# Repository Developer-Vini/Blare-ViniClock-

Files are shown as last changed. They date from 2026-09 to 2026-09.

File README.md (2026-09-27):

# Blare(ViniClock)

# What is ViniClock?

ViniClock is an alarm clock to wake me up whenever I have to go to school; I don't want to miss the bus.

## Some views of the project:

### CASE 3D
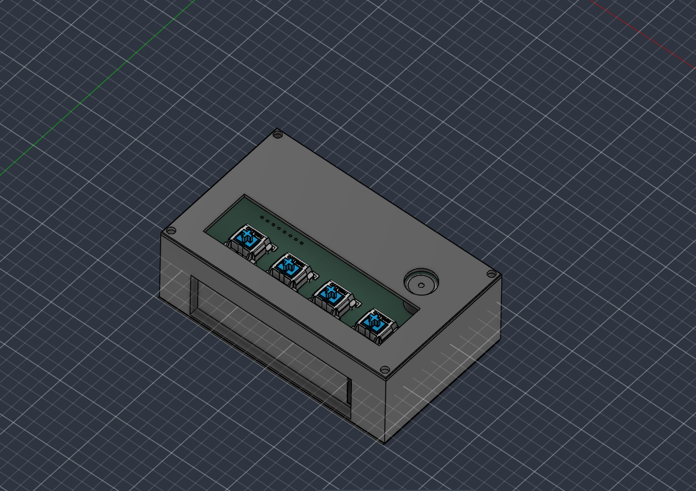
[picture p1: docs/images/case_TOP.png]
top

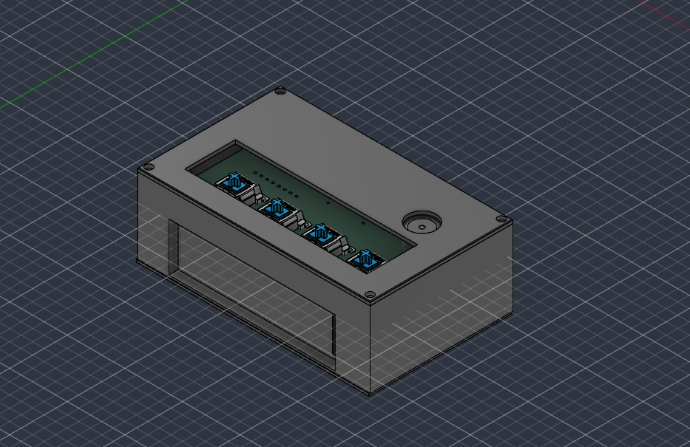
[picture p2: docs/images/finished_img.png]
finished_img


## Assembly CASE 3D:
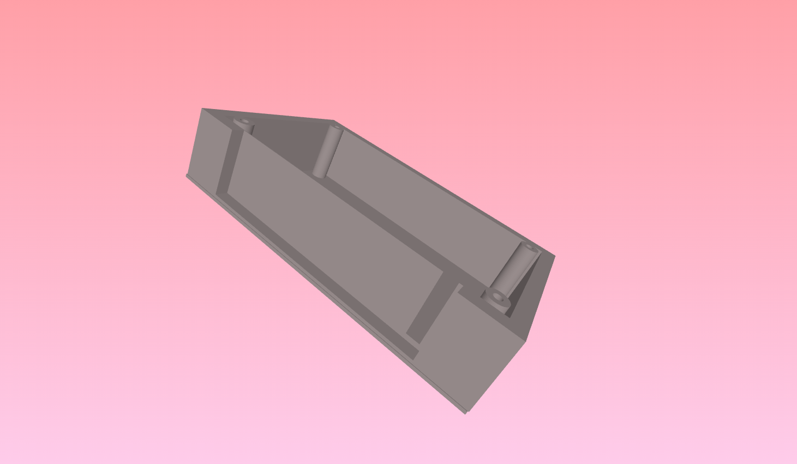
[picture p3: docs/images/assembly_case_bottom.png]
BOTTOM

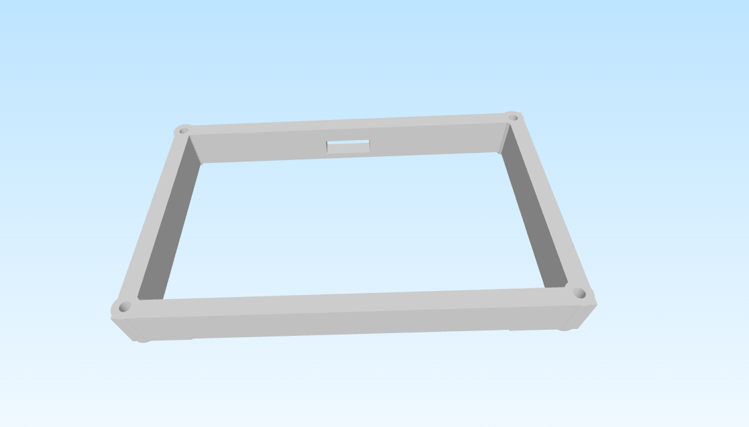
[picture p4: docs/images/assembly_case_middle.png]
MIDDLE

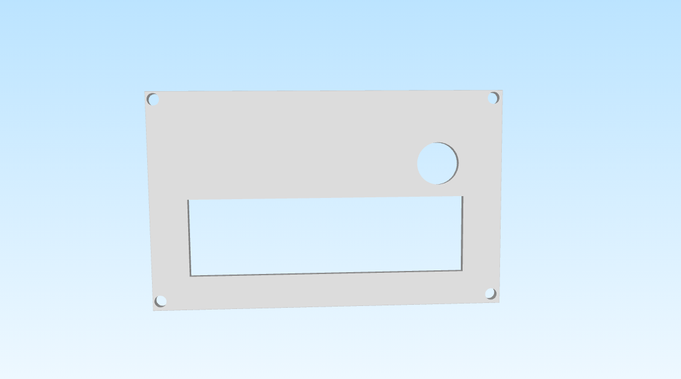
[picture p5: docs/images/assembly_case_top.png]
TOP


### PCB 3d
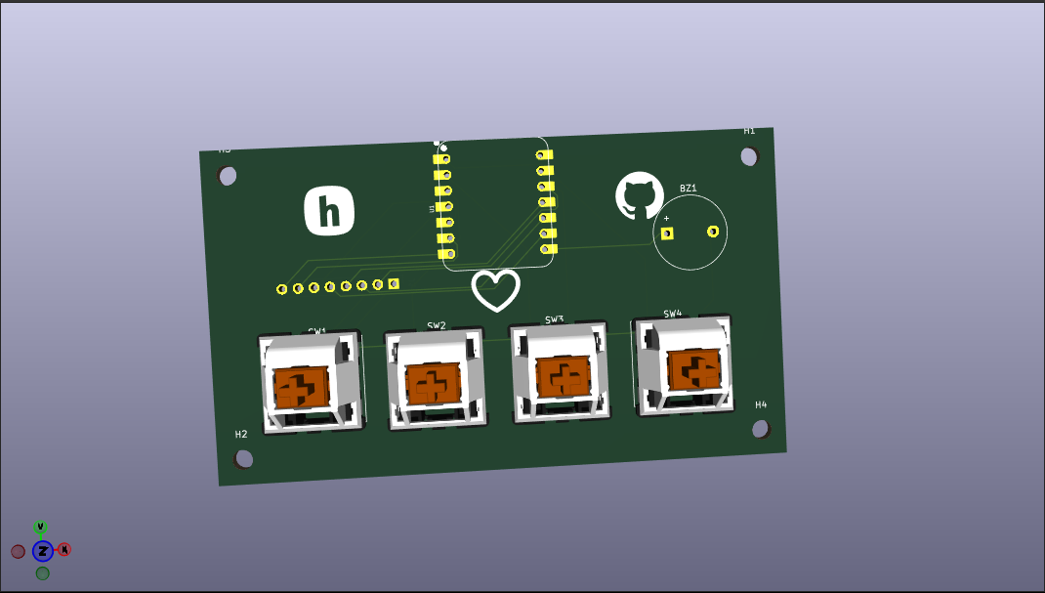
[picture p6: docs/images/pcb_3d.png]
pcb_3d_view

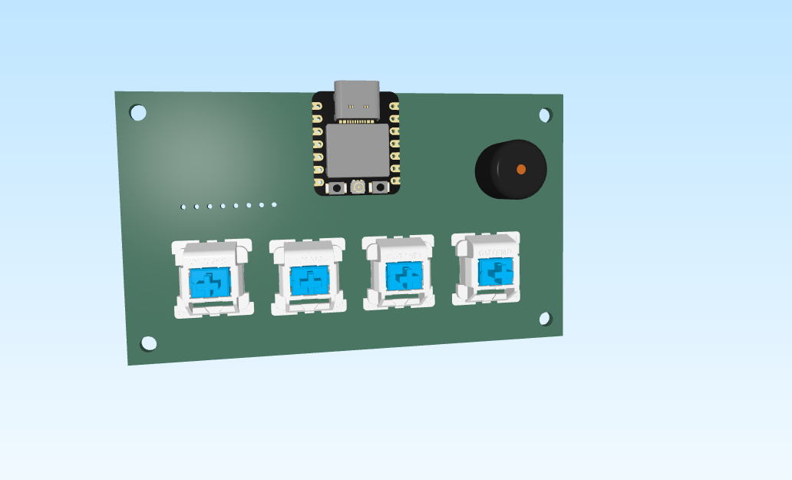
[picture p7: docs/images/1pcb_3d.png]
1pcb_3d_view


### PCB
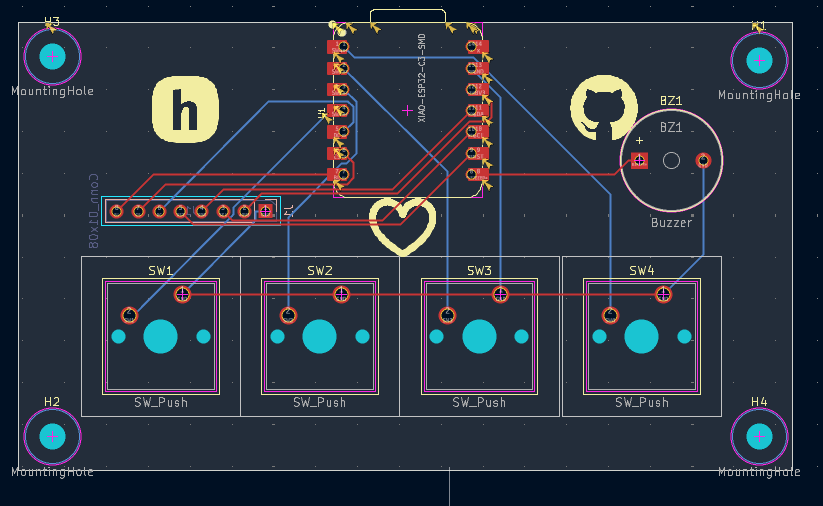
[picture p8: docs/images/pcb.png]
pcb

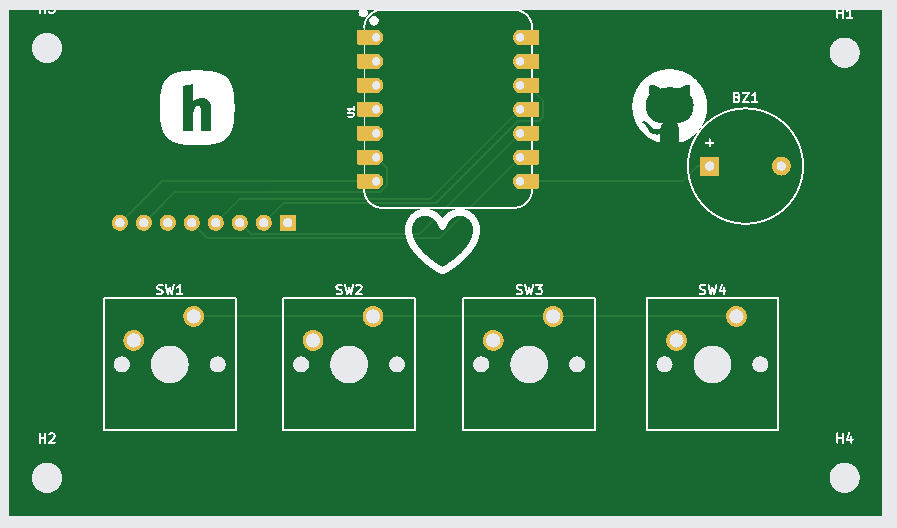
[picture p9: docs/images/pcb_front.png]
pcb_frontal

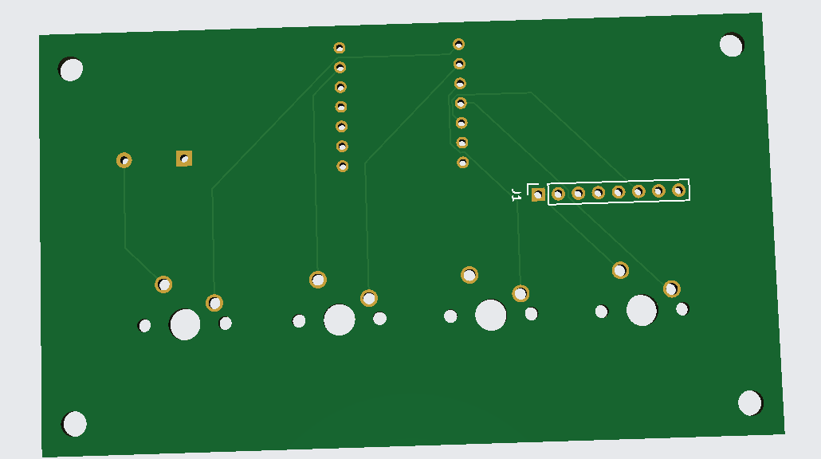
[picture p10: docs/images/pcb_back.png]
pcb_back


### SCHEMATIC 
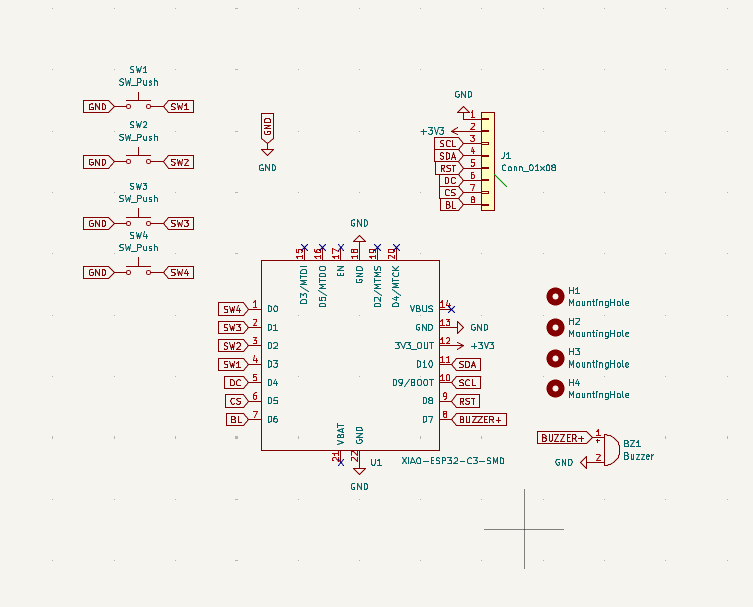
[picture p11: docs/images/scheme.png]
scheme_img


To view the diagram in more detail, download the [PDF](docs/blare.pdf) or open it right here on GitHub.

### Lessons Learned
While developing the project, I learned various concepts and 3D modeling techniques; I learned to use Fusion 360 and how to work with sketches, extrusions, and much more. I also learned—or rather, improved upon—skills in KiCad that I hadn't mastered before. Moving forward, I plan to move away from using labels and instead try wiring things up to create a really neat, organized setup.

# BOM

| Designator | Footprint | Quantity | Value | |
| :--- | :--- | :---: | :--- | :--- |
| BZ1 | Buzzer_12x9.5RM7.6 | 1 | Buzzer | |
| J1 | PinSocket_1x08_P2.54mm_Vertical | 1 | Conn_01x08 | |
| SW1, SW2, SW3, SW4 | SW_Cherry_MX_1.00u_PCB | 4 | SW_Push | |
| U1 | XIAO-ESP32-C3-DIP | 1 | XIAO-ESP32-C3-SMD | |
| TFT | 2.25in TFT Screen | 1 | | |

# Firmware
The code was written entirely in C++—I personally prefer programming in C. It wasn't too hard to write, though I'm not sure if everything is 100% correct; I'll only know for sure once I get the kit and can test it, but my ego tells me it's spot on, haha. I could have tested it on Tinkercad, but it doesn't have the specific components I need.

# Sound
There are also the notes; for now, I'm going to use the Nokia tune because I like it. I got the notes from this blog post: https://blog.eletrogate.com/relogio-despertador-arduino-com-melodia-personalizavel/ I was a bit short on ideas, so I might change it later—I think I'll create my own melody.

# How do I run it?
To run the project, you'll need to install the Arduino IDE—the tool used to upload (flash) the code to the Arduino. Once installed, connect the board to your PC using a USB-C cable (or another compatible one); the option to select the target board for flashing will appear in the top corner of the screen—just select it, and you're all set.
Don't forget to clone the repo, then copy and open my code in the Arduino IDE.

For those of you who are too lazy to do the research yourself, here’s the link served up on a silver platter.
https://support.arduino.cc/hc/en-us/articles/360019833020-Download-and-install-Arduino-IDE

Thanks! I'm going to add the timelapse of the README creation.

<hr>

#### @Developer-Vini
#### Username slack: o_dev

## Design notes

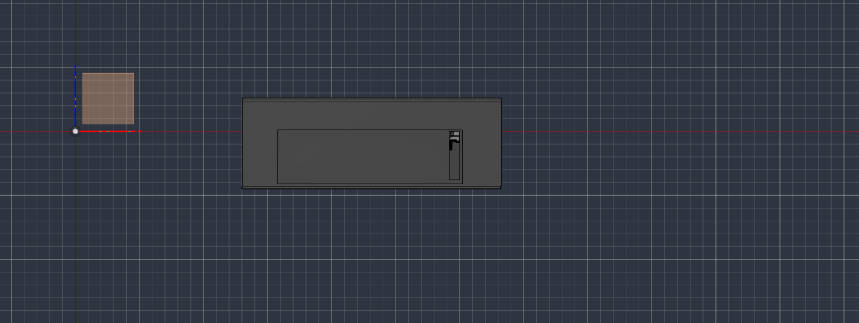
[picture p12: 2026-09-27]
docs/images/case_FRONTAL.png

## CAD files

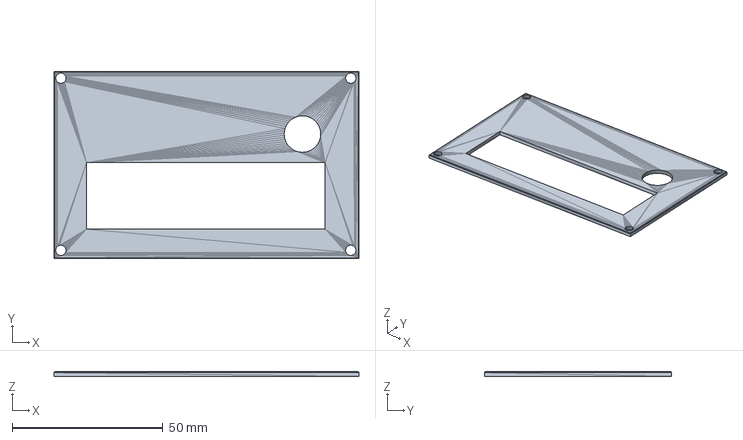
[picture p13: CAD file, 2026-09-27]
CAD/Top.step
101.0 x 62.0 x 1.50 mm

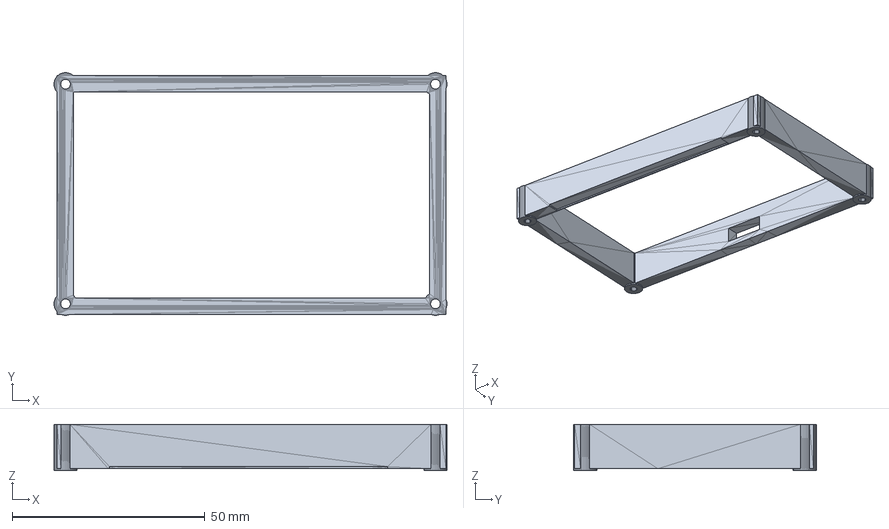
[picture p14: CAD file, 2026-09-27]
CAD/Middle.step
102.0 x 63.0 x 12.0 mm

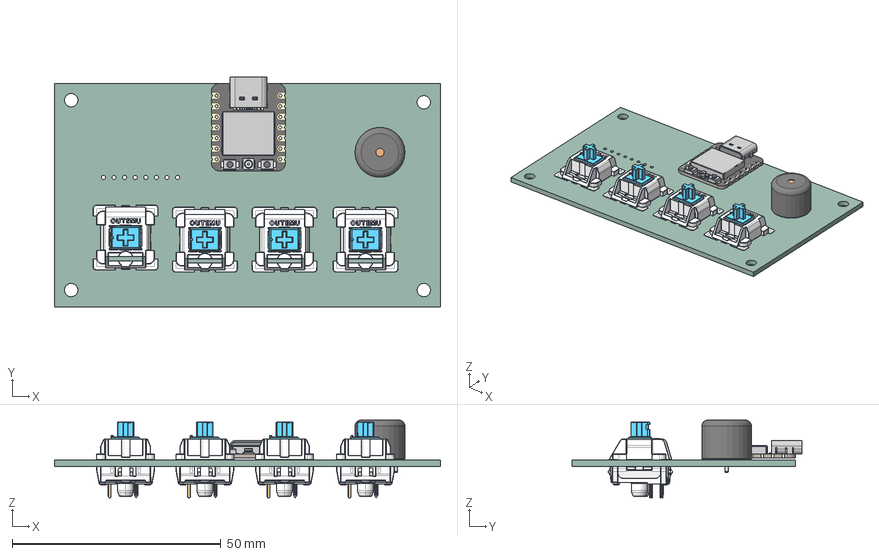
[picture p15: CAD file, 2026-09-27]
CAD/blare.step
92.5 x 55.0 x 18.7 mm
BOTT x 4
PIN x 4
SPRIN x 4
CLICK x 4
RET x 4
TOP x 4
BOSS-EXTRUDE14_8_
BOSS-EXTRUDE7_4_
BOSS-EXTRUDE7_3_
BOSS-EXTRUDE14_4_
BOSS-EXTRUDE14_2_
BOSS-EXTRUDE14_11_
BOSS-EXTRUDE7_7_
BOSS-EXTRUDE14_9_
BOSS-EXTRUDE14_3_
BOSS-EXTRUDE14_7_
MIRROR2
BOSS-EXTRUDE14_5_
BOSS-EXTRUDE14_12_
BOSS-EXTRUDE7_8_
BOSS-EXTRUDE7_1_
BOSS-EXTRUDE14_10_
BOSS-EXTRUDE7_9_
BOSS-EXTRUDE14_6_
BOSS-EXTRUDE14_1_
BOSS-EXTRUDE7_6_
BOSS-EXTRUDE7_2_
CUT-EXTRUDE5
BOSS-EXTRUDE7_5_
U.FL Connector v1
Button (1) x 2
Shield
Buzzer_12x95RM76
blare_PCB

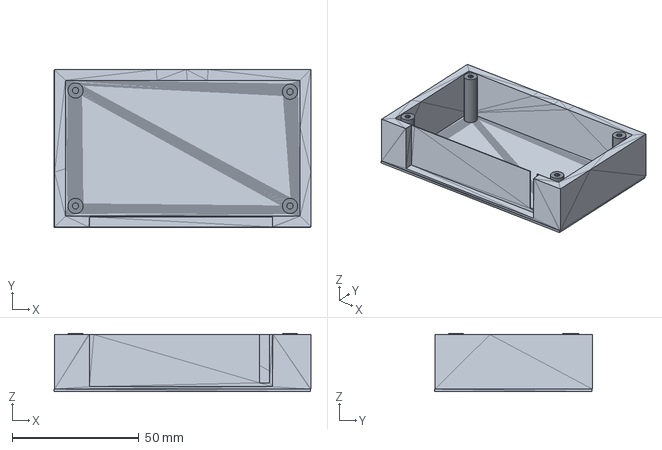
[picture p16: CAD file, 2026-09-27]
CAD/Bottom.step
101.3 x 62.3 x 23.0 mm

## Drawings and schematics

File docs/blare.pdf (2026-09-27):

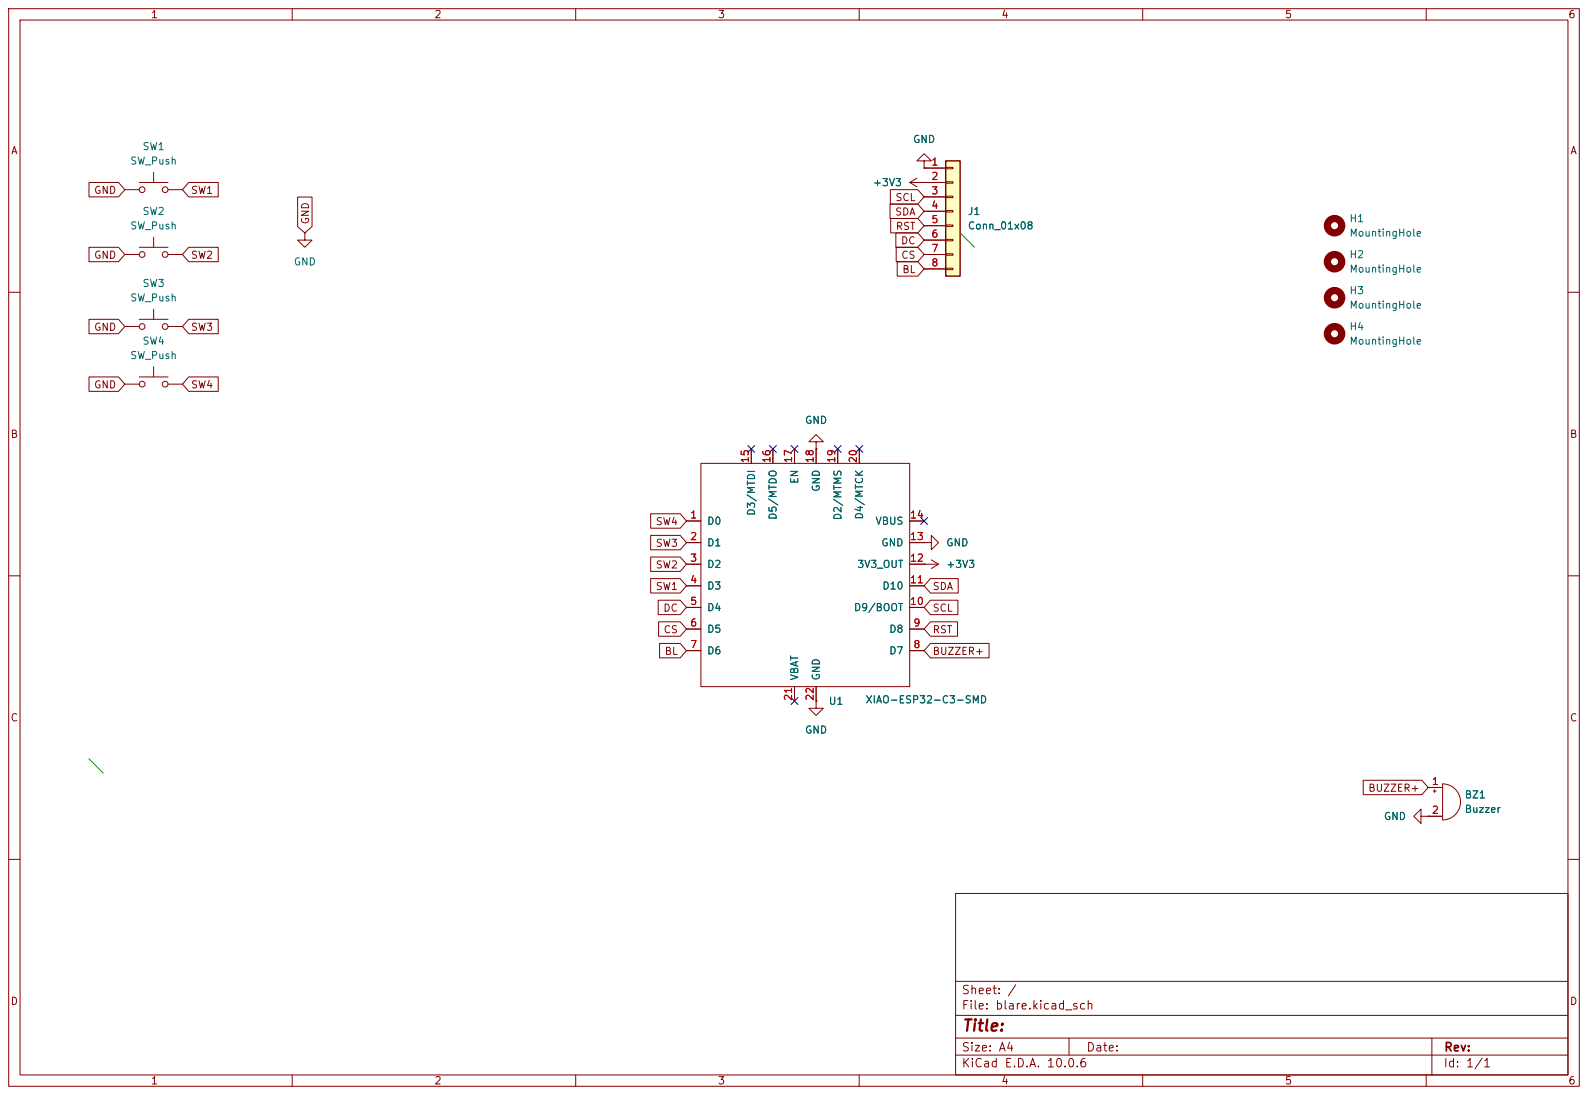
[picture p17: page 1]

SCL RST SDABL CSDC

Size: A4 | Rev:
KiCad E.D.A. 10.0.6 | Id: 1/1

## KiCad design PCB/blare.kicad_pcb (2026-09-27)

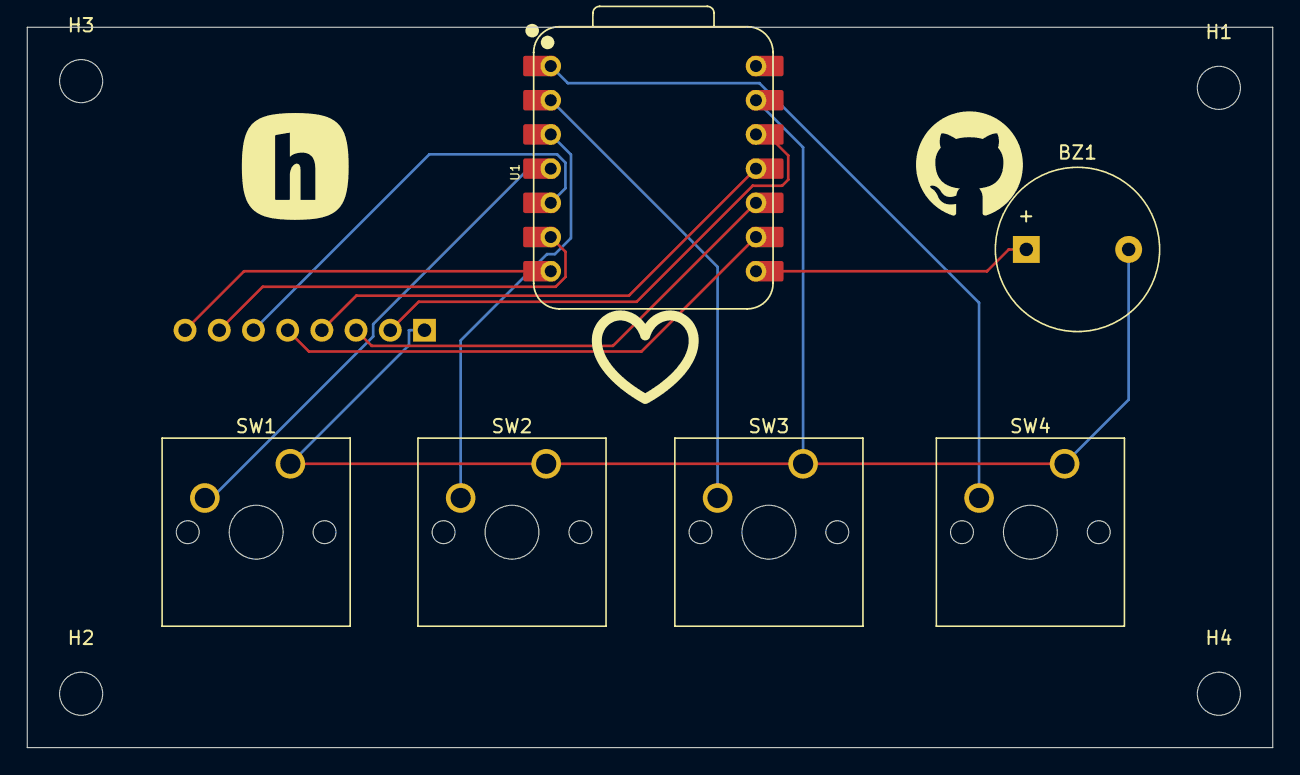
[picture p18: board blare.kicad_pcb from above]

Board: 2 copper layers, 92.5 x 53.5 mm, 11 parts (1 on the bottom side), 13 nets.

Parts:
BZ1: Buzzer; Buzzer_12x9.5RM7.6
H1, H2, H3, H4: MountingHole; MountingHole_3.2mm_M3
J1: Conn_01x08; PinSocket_1x08_P2.54mm_Vertical
SW1, SW2, SW3, SW4: SW_Push; SW_Cherry_MX_1.00u_PCB
U1: XIAO-ESP32-C3-SMD; XIAO-ESP32-C3-DIP

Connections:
+3V3: J1.2, U1.12 (3V3_OUT)
BL: J1.8, U1.7 (D6)
BUZZER+: BZ1.1 (+), U1.8 (D7)
CS: J1.7, U1.6 (D5)
DC: J1.6, U1.5 (D4)
GND: BZ1.2 (-), J1.1, SW1.1, SW2.1, SW3.1, SW4.1, U1.13 (GND)
RST: J1.5, U1.9 (D8)
SCL: J1.3, U1.10 (D9/BOOT)
SDA: J1.4, U1.11 (D10)
SW1: SW1.2, U1.4 (D3)
SW2: SW2.2, U1.3 (D2)
SW3: SW3.2, U1.2 (D1)
SW4: SW4.2, U1.1 (D0)

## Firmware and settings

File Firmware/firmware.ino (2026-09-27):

//I didn't write the code in English because I was focused on the code itself; translating everything would have taken too long.'

#include <Adafruit_GFX.h>
#include <Adafruit_ST7789.h>
#include <SPI.h>
#include <WiFi.h>
#include "time.h"
#include "NotasMusicais.h"

#define TFT_SCLK 9
#define TFT_MOSI 10
#define TFT_RST 8
#define TFT_DC 4
#define TFT_CS 5
#define TFT_BL 21

#define BTN_SELECT 5
#define BTN_UP 4
#define BTN_DOWN 3
#define BTN_BACK 2

#define BUZZER_PIN 20

const char *WIFI_SSID = "";
const char *WIFI_PASSWORD = "";
const char *NTP_SERVER = "";
const long GMT_OFSSET_S = -3 * 3600;
const int DST_OFFSET_S = 0;

#define COR_DE_FUNDO 0x0000
#define COR_HORA 0x07FF
#define COR_DATA 0xFFF
#define COR_DESTAQUE 0xFFE0
#define COR_ALARME_ON 0x07E0
#define COR_ALARME_OFF 0xF800

Adafruit_ST7789 tft = Adafruit_ST7789(TFT_CS, TFT_DC, TFT_MOSI, TFT_SCLK, TFT_RST);
Tela telaAtual = TELA_RELOGIO;

enum Tela
{
  TELA_RELOGIO,
  TELA_MENU,
  TELA_AJUSTE_ALARME,
  TELA_TOCANDO
};

int alarmeHora = 7;
int alareMinuto = 0;
bool alarmeAtivo = true;
bool jaTocouNesseMinuto = false;

int w = 240
int h = 320

int menuIndex = 0;
const char *menuItens[] = {
    "Ativar/Desativaor",
    "Ajustar Hora",
    "Ajustar Minuto"."Voltar"};

const int totalMenuItens = 4;

int melodia[] = {
    NOTE_E5,
    NOTE_D5, 
    NOTE_FS4, 
    NOTE_GS4, 
    NOTE_GS4, 
    NOTE_CS5, 
    NOTE_B4, 
    NOTE_D4, 
    NOTE_E4, 
    NOTE_B4, 
    NOTE_A4, 
    NOTE_CS4, 
    NOTE_E4, 
    NOTE_A4, 
    NO_SOUND
} 
int totalNotas = 15;

void setup()
{
  Serial.begin(115200);

  pinMode(BTN_UP, INPUT_PULLUP);
  pinMode(BTN_DOWN, INPUT_PULLUP);
  pinMode(BTN_SELECT, INPUT_PULLUP);
  pinMode(BTN_BACK, INPUT_PULLUP);
  pinMode(TFT_BL, OUTPUT);
  analogWrite(TFT_BL, 255)

  tft.init(w, h);
  tft.setRotation(2);
  tft.fillScren(COR_DE_FUNDO);

  mostrarSplash();
  conectarWiFi();
}

void loop(){
  // put your main code here, to run repeatedly:
  struct tm agora;
  bool temHora = getLocalTime(&agora);

  switch (telaAtual){
  case TELA_RELOGIO:
    desenharTelaRelogio(agora, temHora);
    if (botaoPressionado(BTN_SELECT)){
      telaAtual = TELA_MENU;
      tft.fillScreen(COR_DE_FUNDO);
    }
  }else{
    jaTocouNesseMinuto = false;
  }
  break;

  case TELA_AJUSTE_ALARME:
    desenharMenu();
    if (botaopressionado(BTN_UP)) menuIndex = (menuIndex - 1 + totalMenuItens) % totalMenuItens;
    if (botaopressionado(BTN_DOWN)) menuIndex = (menuIndex + 1) % totalMenuItens;
    if (botaopressionado(BTN_SELECT)){
      executarOpcaoMenu();
    }
    if (botaopressionado(BTN_BACK)){
      telaAtual = TELA_RELOGIO;
      tft.fillScreen(COR_DE_FUNDO);
    }
  break;

  case TELA_TOCANDO:
    tocarAlarme();
    break;
}


void mostrarSplash(){
  tft.setTextColor(COR_DESTAQUE);
  tft.setTextSize(2)
  tft.setCursor(20, 100);
  tft.print("Blare Vini");
  delay(1200);
  tft.fillScreen(COR_DE_FUNDO)
}
void conectarWiFi(){
  tft.setCursor(10, 10);
  tft.setTextColor(COR_DATA);
  tft.setTextSize(1);
  tft.print("Conectando no WiFi...");

  WiFi.begin(WIFI_SSID, WIFI_PASSWORD);
  int tentativas = 0;
  //tft.setTextSize()
  while(WiFi.status != WL_CONNECTED && tentativas = 10){
    delay(500);
    Serial.print(".");
    tentativas++;
  }

  if(WiFi.status() == WL_CONNECTED){
    confiTime(GMT_OFSSET_S, DST_OFFSET_S, NTP_SERVER);
    tft.fillScreen(COR_DE_FUNDO);
  }else{
    tft.fillScreen(COR_DE_FUNDO);
    tft.setCursor(10, 10);
    tft.setTextColor(COR_ALARME_OFF);
    tft.print("Sem WiFi - hora manual");
    delay(1500);
    tft.fillScreen(COR_DE_FUNDO);
  }
}
void desenharTelaRelogio(){
    tft.fillRect(0, 0, w, h, COR_DE_FUNDO);

    tft.setTextSize(5);
    tft.setTextColor(COR_HORA);
    tft.setCursor(30, 80);
    if(temHora) {
      if(agora.tm_hour < 10) tft.print("0");
      tft.print(agora.tm_hour);
      tft.print(":");
      if(agora.tm_min < 10) tft.print("0");
      tft.print(agora.tm_min);
    }else{
      tft.print("--:--");
    }

    tft.setTextSize(1);
    tft.setTextColor(COR_DATA);
    tft.setCursor(60, 140);
    if(temHora){
      tft.printf("%02d/%02d/%04d", agora.tm_mday, agora.tm_mon + 1, agora.tmm_year + 1900);
    }

    tft.setCursor(50, 200);
    tft.setTextColor(alarmeAtivo ? COR_ALARME_ON : COR_ALARME_OFF);
    tft.printf("Alarme %02d/%02d %s", alarmeHora, alareMinuto, alarmeAtivo ? "ON" : "OFF");
}
void desenharmenu(){
  tft.fillRect(0,0, w,h, COR_DE_FUNDO);
  tft.setTextSize(2);
  tft.setCursor(50, 10);
  tft.setTextColor(COR_DESTAQUE);
  tft.print("MENU");

  for(int i=0;i<totalMenuItens;i++){
    tft.setCursor(20, 50 + i * 30);
    tft.setTextColor(i == menuIndex ?COR_DESTAQUE : COR_DATA);
    tft.print(i == menuIndex ? ">":"");
    tft.print(menuItens[i]);
  }
} 
void executarOpcaoMenu() {
  switch(menuIndex){
    case 0:
      alarmeAtivo = !alarmeAtivo;
    break;
    case 1:
      telaAtual = TELA_AJUSTE_ALARME;
      tft.fillScreen(COR_DE_FUNDO);
    break;
    case 2:
      telaAtual = TELA_AJUSTE_ALARME;
      tft.fillScreen(COR_DE_FUNDO);
    break;
    case 3:
      telaAtual = TELA_RELOGIO;
      tft.fillScreen(COR_DE_FUNDO);
      break;
    }
}
void desenharAjusteAlarme() {
  tft.fillRect(0, 0, 240, 240, COR_DE_FUNDO);
  tft.setTextSize(2);
  tft.setCursor(20, 20);
  tft.setTextColor(COR_DESTAQUE);
  tft.print("Ajustar Alarme");

  tft.setTextSize(4);
  tft.setCursor(50, 100);
  tft.setTextColor(COR_HORA);
  tft.printf("%02d:%02d", alarmeHora, alarmeMinuto);

  tft.setTextSize(1);
  tft.setCursor(20, 200);
  tft.setTextColor(COR_DATA);
  tft.print("UP/DOWN: minuto | SELECT: voltar");
}

void tocarAlarme() {
  tft.fillScreen(COR_ALARME_OFF);
  tft.setTextSize(3);
  tft.setTextColor(0xFFFF);
  tft.setCursor(30, 90);
  tft.print("ACORDA!");

  for (int i = 0; i < totalNotas; i++) {
    tone(BUZZER_PIN, melodia[i], 250);
    unsigned long inicio = millis();
    while (millis() - inicio < 300) {
      if (digitalRead(BTN_BACK) == LOW || digitalRead(BTN_SELECT) == LOW) {
        noTone(BUZZER_PIN);
        jaTocouNesseMinuto = true;
        telaAtual = TELA_RELOGIO;
        tft.fillScreen(COR_DE_FUNDO);
        return;
      }
    }
  }
  noTone(BUZZER_PIN);
}
bool botaoPressionado(int pino) {
  if (digitalRead(pino) == LOW && (millis() - ultimoDebounce) > debounceDelay) {
    ultimoDebounce = millis();
    return true;
  }
  return false;
}

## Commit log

2026-09-27 feat: finalizing the firmware code
    [Bottom.step, Middle.step, Top.step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]
2026-09-27 feat(firmware): add sounds alarm and button pressed function
2026-10-21 Reformat BOM table in README.md for clarity
2026-10-22 Add 3D PCB images to README
2026-10-22 Revise BOM format and add new components
    Updated the Bill of Materials (BOM) section to include additional components and their quantities.
2026-10-22 feat: delete CAD directory
2026-10-22 feat: delete CAD/.gitkeep
2026-10-22 feat: update README with assembly notes
    Added a note about gluing the top instead of using screws.
2026-10-23 feat: revise BOM and remove redundant designator table
    Updated BOM section with detailed component descriptions and quantities. Removed redundant designator table and added notes about assembly and firmware.
2026-10-23 feat: revise bom.csv to include new components
    Updated BOM with additional components and corrected formatting.
2026-10-23 Change BOM file to CSV format
    Updated BOM file format to use commas instead of tabs.
2026-10-23 Update bom.csv with new component details
